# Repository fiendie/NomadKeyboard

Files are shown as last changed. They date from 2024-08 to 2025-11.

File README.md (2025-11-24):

# Nomad Keyboard

The Nomad is a 7×5 keys, column-staggered split keyboard based in part on the [Sofle Choc by Brian Low](https://github.com/brianlow/SofleKeyboard).
It uses low profile Kailh Choc v1 switches with hotswap sockets and features per-key RGB lighting via SK6812 Mini-E LEDs.
Compared to the Sofle Choc the nomad offers an additional thumb cluster key, an additional modifier key in the 5th row and a 7th inner column with 3 keys each.
An MX version is also available.

If you are a non-EU resident you can buy pre-made keyboards from [Lucky Boy Store](https://www.aliexpress.com/item/1005009922158971.html) on AliExpress.

## Table of Contents

- [Firmware](#firmware)
- [Bill of Materials](#bill-of-materials)
- [Default Layout](#default-layout)
- [Build Instructions](#build-instructions)
- [Images](#images)

## Firmware 

Nomad uses [QMK firmware](https://github.com/fiendie/qmk_firmware/tree/nomad)

Currently there is a default keymap for and a vial keymap to configure your keyboard in real time.

## Bill of Materials

| **Item** | **Quantity** | **Notes** |
|---|---|---|
| **Nomad PCB** | 2 | Custom left and right halves. |
| **Kailh Choc v1 or MX switches** | 68 | Choose based on version, the Choc version is only compatible with v1 switches!. |
| **Keycaps (MBK, ChocFox, or MX)** | 68 | Must match switch type and profile preference. |
| **SMD Diodes (1N4148, 0805 package)** | 68 | One per switch; surface-mount only. |
| **SK6812 Mini-E LEDs** | 68 | One per switch, make sure you get the Mini-E version specifically. |
| **RP2040 Controller** | 2 | Tested with SplitKB Liatris and 42.Keebs Frood. |
| **TRRS jacks** | 2 | For inter-half communication. |
| **TRRS cable** | 1 | Male-to-male, preferrably with 90 degree plugs |
| **ALPS EC12 Low-Profile Rotary Encoder** | 2 | Optional rotary input. |
| **Tactile Reset Button** | 2 | Optional but useful. |
| **OLED Display (SSD1306 128x32)** | 2 (optional) | Optional I2C displays. |
| **SMD Resistors (0805 package)** | 4 | I2C pull-up resistors, ony needed for the displays |
| **Header Pins** | Varies | For MCU, OLEDs. |
| **3D-Printed Case** | 2 halves | Top shell only; open-bottom design using included STL files. |
| **Acrylic Cover** | 2 halves | Laser-cut cover layer using included DXF file. |
| **M2 Standoffs (12 mm)** | 8 | For mounting cover to case. |
| **M2 Countersunk Screws (top)** | 8 | For securing the acrylic cover to standoffs. |
| **M2 Hex Screws (bottom of standoffs)**  | 8 | Attach standoffs from underneath the case edge. |
| **Rubber feet** | 8+ | Optional, for grip and elevation. |

## Default layout 

**Base Layer**
```
┌──────┬─────┬─────┬─────┬─────┬─────┬─────┐                ┌─────┬─────┬─────┬─────┬─────┬─────┬──────┐
│ Esc  │  1  │  2  │  3  │  4  │  5  │  <  │                │  >  │  6  │  7  │  8  │  9  │  0  │ Bksp │
├──────┼─────┼─────┼─────┼─────┼─────┼─────┤                ├─────┼─────┼─────┼─────┼─────┼─────┼──────┤
│ Tab  │  Q  │  W  │  E  │  R  │  T  │  {  │                │  }  │  Z  │  U  │  I  │  O  │  P  │  ?   │
├──────┼─────┼─────┼─────┼─────┼─────┼─────┤                ├─────┼─────┼─────┼─────┼─────┼─────┼──────┤
│  =   │  A  │  S  │  D  │  F  │  G  │  |  │                │  -  │  H  │  J  │  K  │  L  │  +  │  #   │
├──────┼─────┼─────┼─────┼─────┼─────┼─────┘                └─────┼─────┼─────┼─────┼─────┼─────┼──────┤
│ LSft │  Y  │  X  │  C  │  V  │  B  │                            │  N  │  M  │  ,  │  .  │  ↑  │ RSft │
├──────┼─────┼─────┼─────┼─────┼─────┼─────┬─────┐    ┌─────┬─────┼─────┼─────┼─────┼─────┼─────┼──────┤
│ Ctrl │ L3  │ L2  │ Opt │ GUI │     │ Spc │ Del │    │ L1  │ Rtn │     │ GUI │ Opt │  ←  │  ↓  │  →   │
└──────┴─────┴─────┴─────┴─────┘     └─────┴─────┘    └─────┴─────┘     └─────┴─────┴─────┴─────┴──────┘
```
**Symbol Layer**
```
┌──────┬─────┬─────┬─────┬─────┬─────┬─────┐                ┌─────┬─────┬─────┬─────┬─────┬─────┬──────┐
│      │     │     │     │     │     │  ^  │                │  °  │     │     │     │     │     │      │
├──────┼─────┼─────┼─────┼─────┼─────┼─────┤                ├─────┼─────┼─────┼─────┼─────┼─────┼──────┤
│      │  Q  │     │  €  │     │     │  [  │                │  ]  │     │  Ü  │     │  Ö  │     │      │
├──────┼─────┼─────┼─────┼─────┼─────┼─────┤                ├─────┼─────┼─────┼─────┼─────┼─────┼──────┤
│      │  Ä  │  ß  │     │     │     │  \  │                │  /  │  H  │     │     │  @  │     │      │
├──────┼─────┼─────┼─────┼─────┼─────┼─────┘                └─────┼─────┼─────┼─────┼─────┼─────┼──────┤
│      │     │     │     │     │     │                            │  ~  │     │     │     │     │      │
├──────┼─────┼─────┼─────┼─────┼─────┼─────┬─────┐    ┌─────┬─────┼─────┼─────┼─────┼─────┼─────┼──────┤
│      │     │     │     │     │     │     │     │    │     │     │     │     │     │     │     │      │
└──────┴─────┴─────┴─────┴─────┘     └─────┴─────┘    └─────┴─────┘     └─────┴─────┴─────┴─────┴──────┘
```
**FN/Media Layer**
```
┌──────┬─────┬─────┬─────┬─────┬─────┬─────┐                ┌─────┬─────┬─────┬─────┬─────┬─────┬──────┐
│      │ F1  │ F2  │ F3  │ F4  │ F5  │ F6  │                │ F7  │ F8  │ F9  │ F10 │ F11 │ F12 │      │
├──────┼─────┼─────┼─────┼─────┼─────┼─────┤                ├─────┼─────┼─────┼─────┼─────┼─────┼──────┤
│      │     │     │     │     │     │     │                │ B+  │     │     │     │     │     │      │
├──────┼─────┼─────┼─────┼─────┼─────┼─────┤                ├─────┼─────┼─────┼─────┼─────┼─────┼──────┤
│      │     │     │     │     │     │     │                │ B-  │     │     │     │     │     │      │
├──────┼─────┼─────┼─────┼─────┼─────┼─────┘                └─────┼─────┼─────┼─────┼─────┼─────┼──────┤
│      │     │     │     │     │     │                            │     │     │     │     │ PgU │ Ins  │
├──────┼─────┼─────┼─────┼─────┼─────┼─────┬─────┐    ┌─────┬─────┼─────┼─────┼─────┼─────┼─────┼──────┤
│      │     │     │     │ Rwd │     │ Pla │ Mut │    │ V-  │ V+  │     │ Fwd │     │ Hom │ PgD │ End  │
└──────┴─────┴─────┴─────┴─────┘     └─────┴─────┘    └─────┴─────┘     └─────┴─────┴─────┴─────┴──────┘
```
**RGB Settings Layer**
```
┌──────┬─────┬─────┬─────┬─────┬─────┬─────┐                ┌─────┬─────┬─────┬─────┬─────┬─────┬──────┐
│      │     │     │     │     │     │ Tgl │                │     │     │     │     │     │     │      │
├──────┼─────┼─────┼─────┼─────┼─────┼─────┤                ├─────┼─────┼─────┼─────┼─────┼─────┼──────┤
│      │     │     │     │     │     │ Md- │                │ Md+ │     │     │     │     │     │      │
├──────┼─────┼─────┼─────┼─────┼─────┼─────┤                ├─────┼─────┼─────┼─────┼─────┼─────┼──────┤
│      │     │     │     │     │     │ Sp- │                │ Sp+ │     │     │     │     │     │      │
├──────┼─────┼─────┼─────┼─────┼─────┼─────┘                └─────┼─────┼─────┼─────┼─────┼─────┼──────┤
│      │     │     │     │     │     │                            │     │     │     │     │     │      │
├──────┼─────┼─────┼─────┼─────┼─────┼─────┬─────┐    ┌─────┬─────┼─────┼─────┼─────┼─────┼─────┼──────┤
│      │     │     │     │ Va- │     │ H-  │ H+  │    │ S-  │ S+  │     │ Va+ │     │     │     │      │
└──────┴─────┴─────┴─────┴─────┘     └─────┴─────┘    └─────┴─────┘     └─────┴─────┴─────┴─────┴──────┘
```

## Build Instructions

Still a work in progress

## Images
Nomad Keyboard Left Half
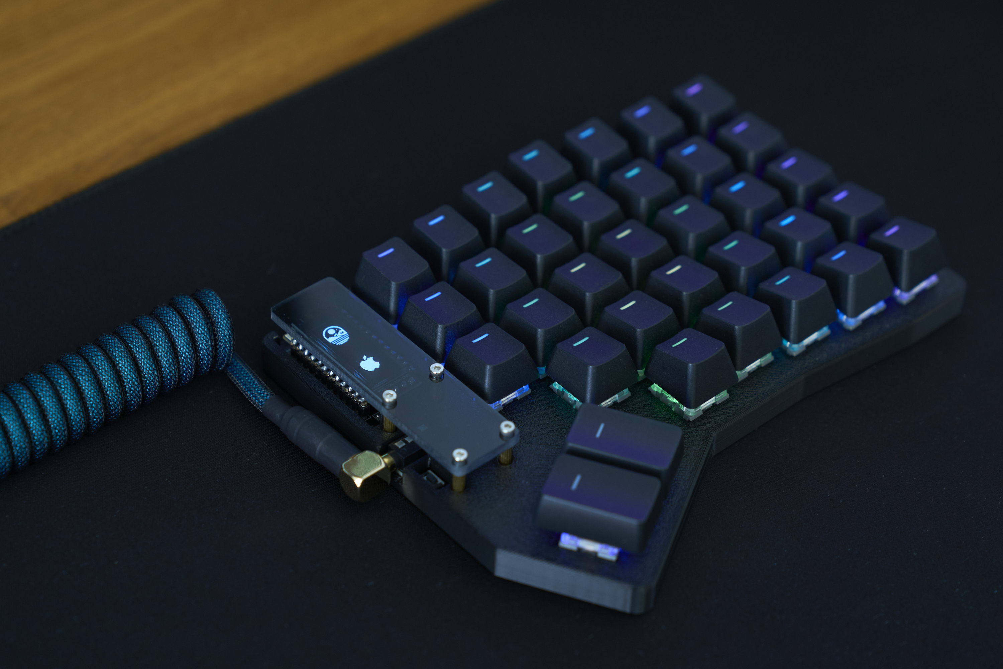
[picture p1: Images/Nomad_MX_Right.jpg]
Nomad Keyboard Left Half

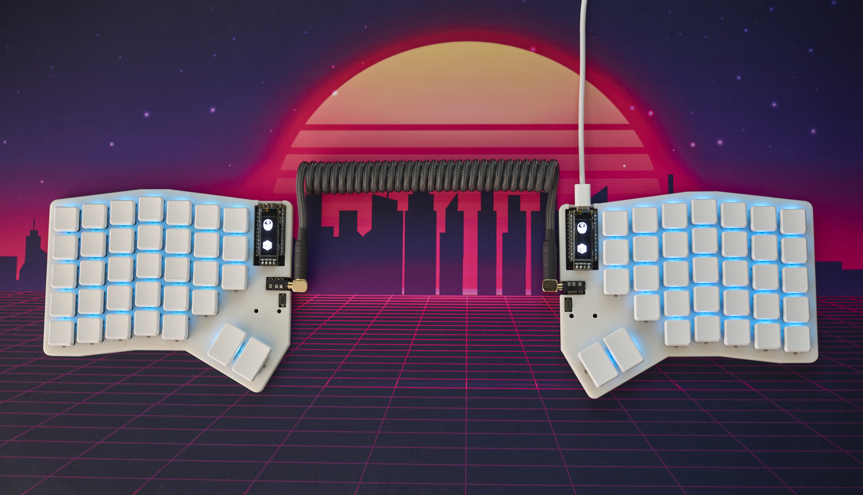
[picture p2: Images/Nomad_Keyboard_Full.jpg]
Nomad Keyboard Left Half

Nomad Keyboard PCB with Switches
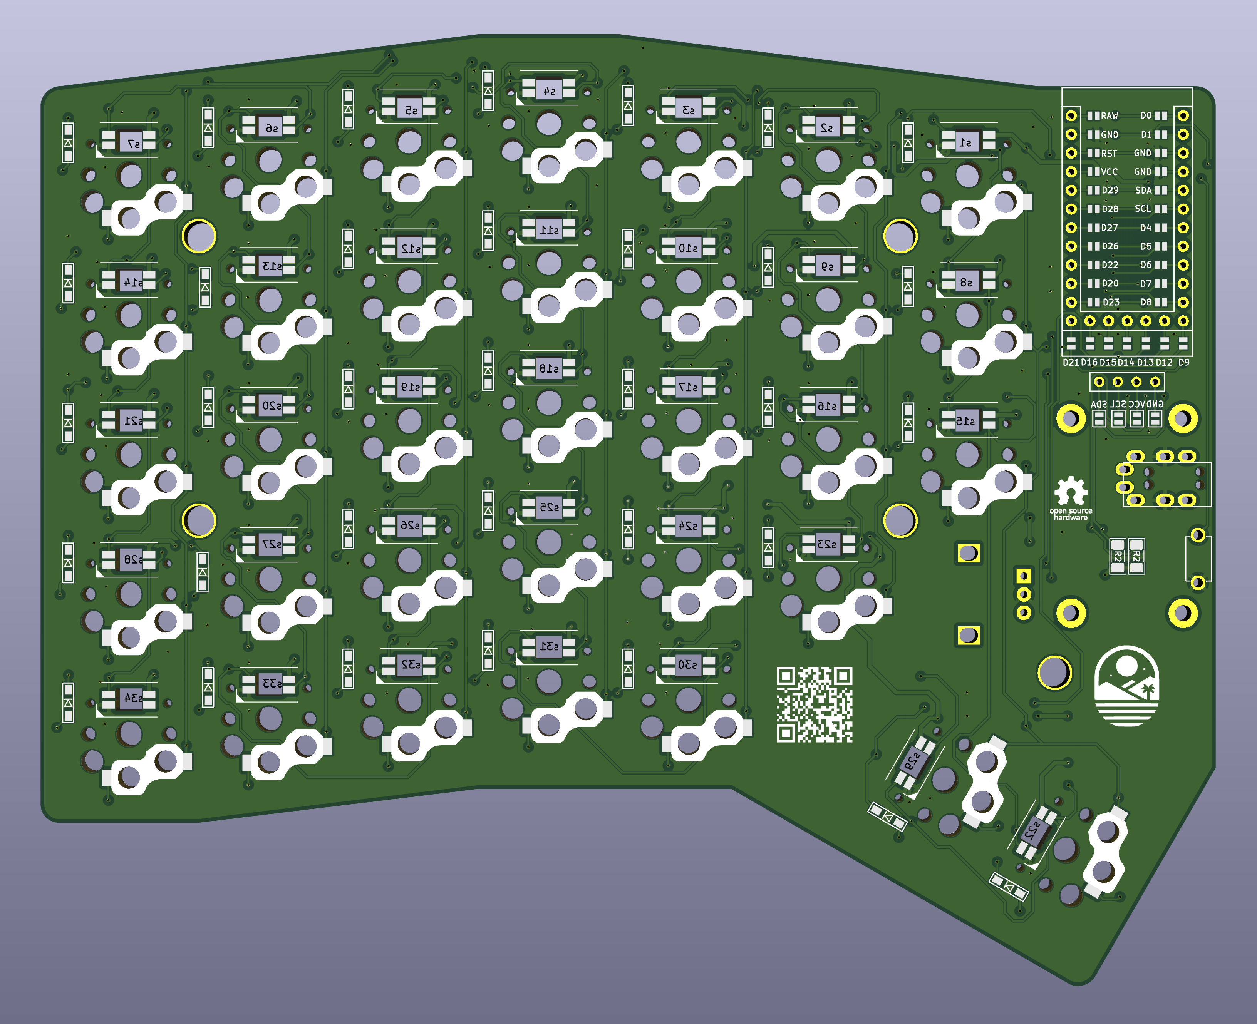
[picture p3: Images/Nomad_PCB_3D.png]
Nomad Keyboard PCB 3D View

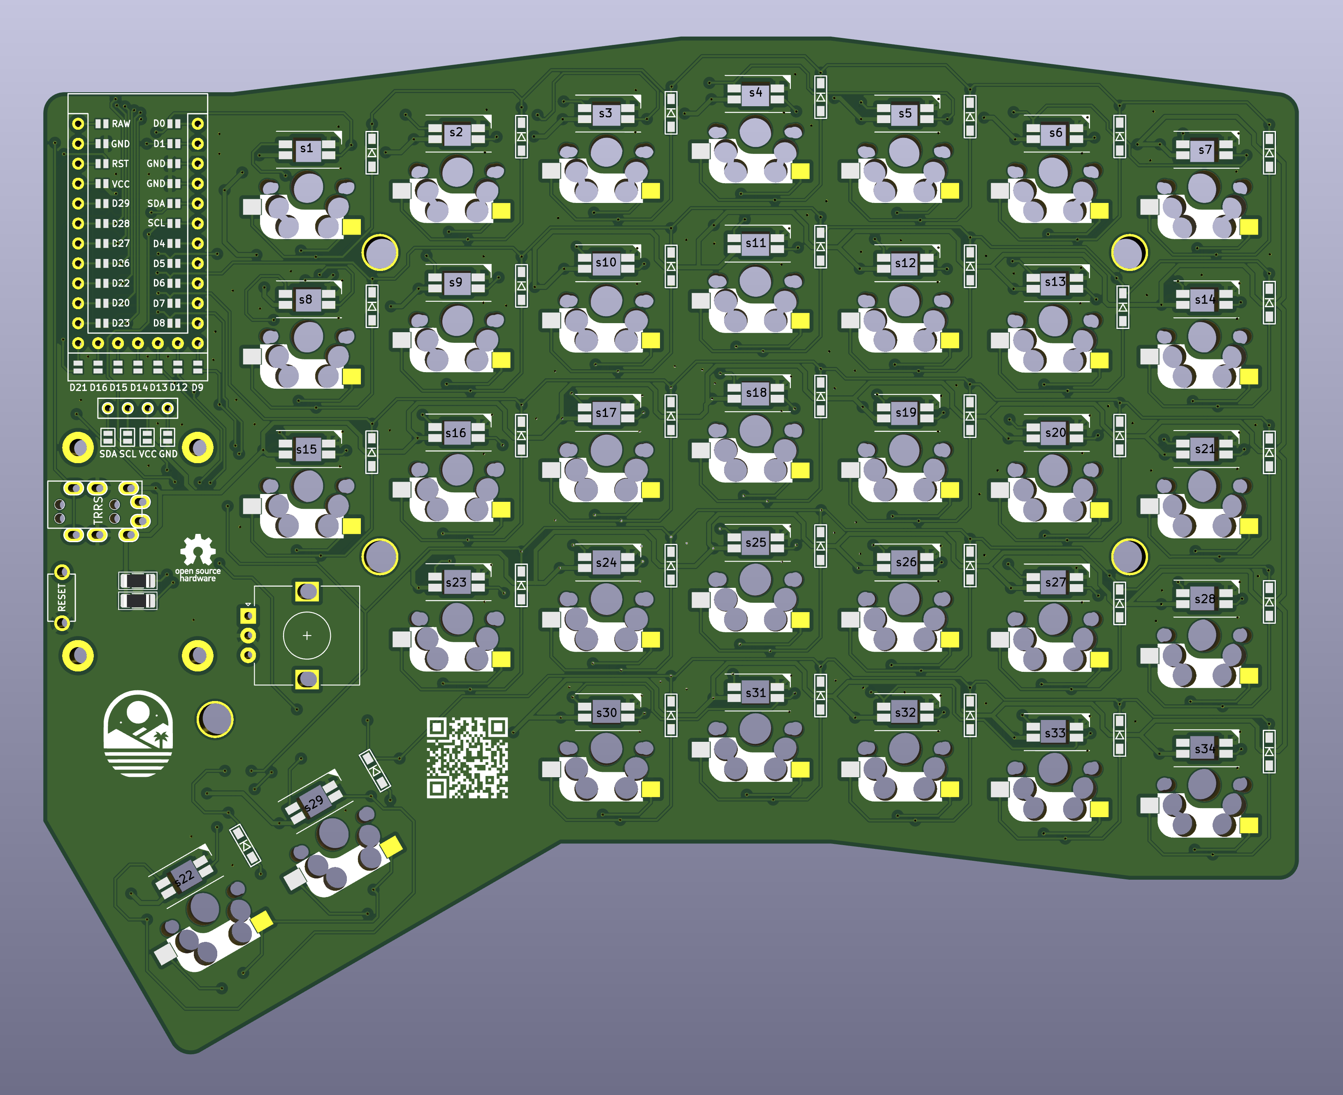
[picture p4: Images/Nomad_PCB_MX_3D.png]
Nomad Keyboard PCB 3D View


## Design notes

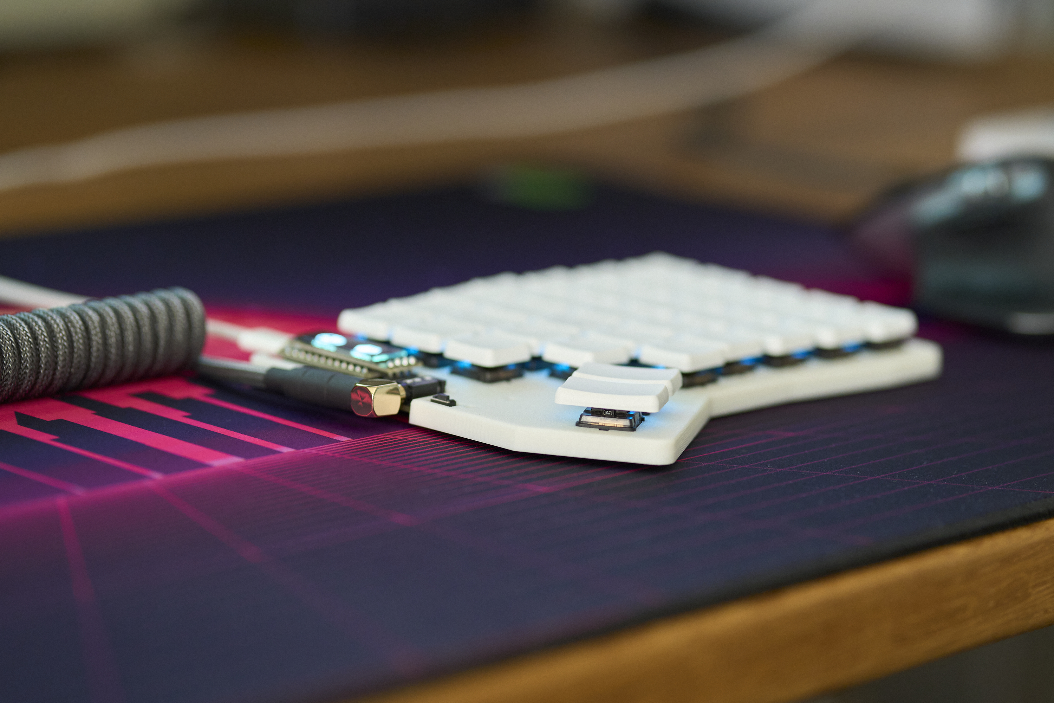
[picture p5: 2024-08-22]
Images/Nomad_Keyboard_Profile.jpg

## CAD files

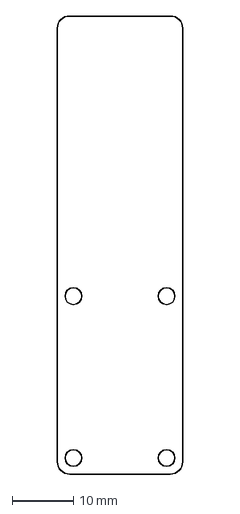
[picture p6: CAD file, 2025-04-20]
Case/Nomad_Display_Cover.dxf
20.5 x 75.0 mm

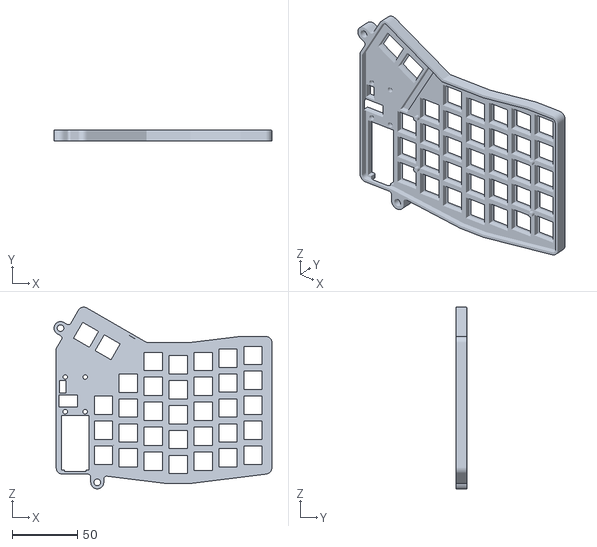
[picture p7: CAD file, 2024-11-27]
Case/Nomad_Keyboard_MX_Tenting_Case.stl
166.6 x 8.75 x 138.9

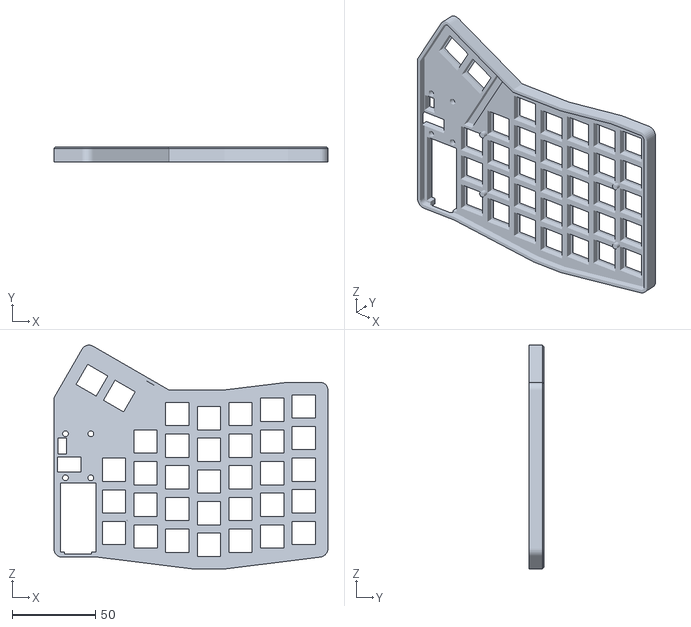
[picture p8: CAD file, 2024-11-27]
Case/Nomad_Keyboard_MX Case.stl
164.9 x 8.75 x 134.8

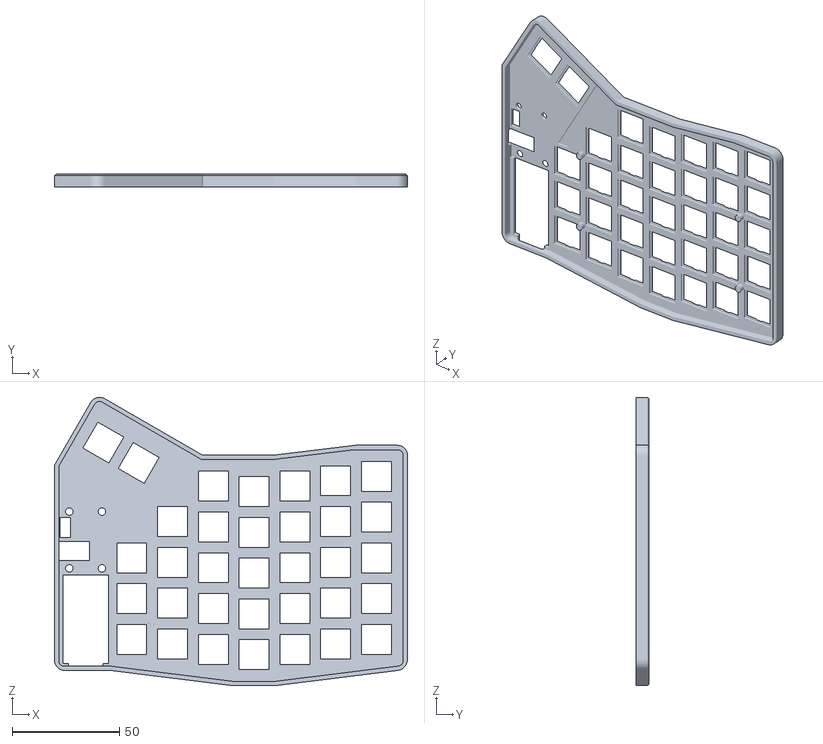
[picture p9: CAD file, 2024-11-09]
Case/Nomad_Keyboard_Case.stl
164.9 x 6.00 x 134.8

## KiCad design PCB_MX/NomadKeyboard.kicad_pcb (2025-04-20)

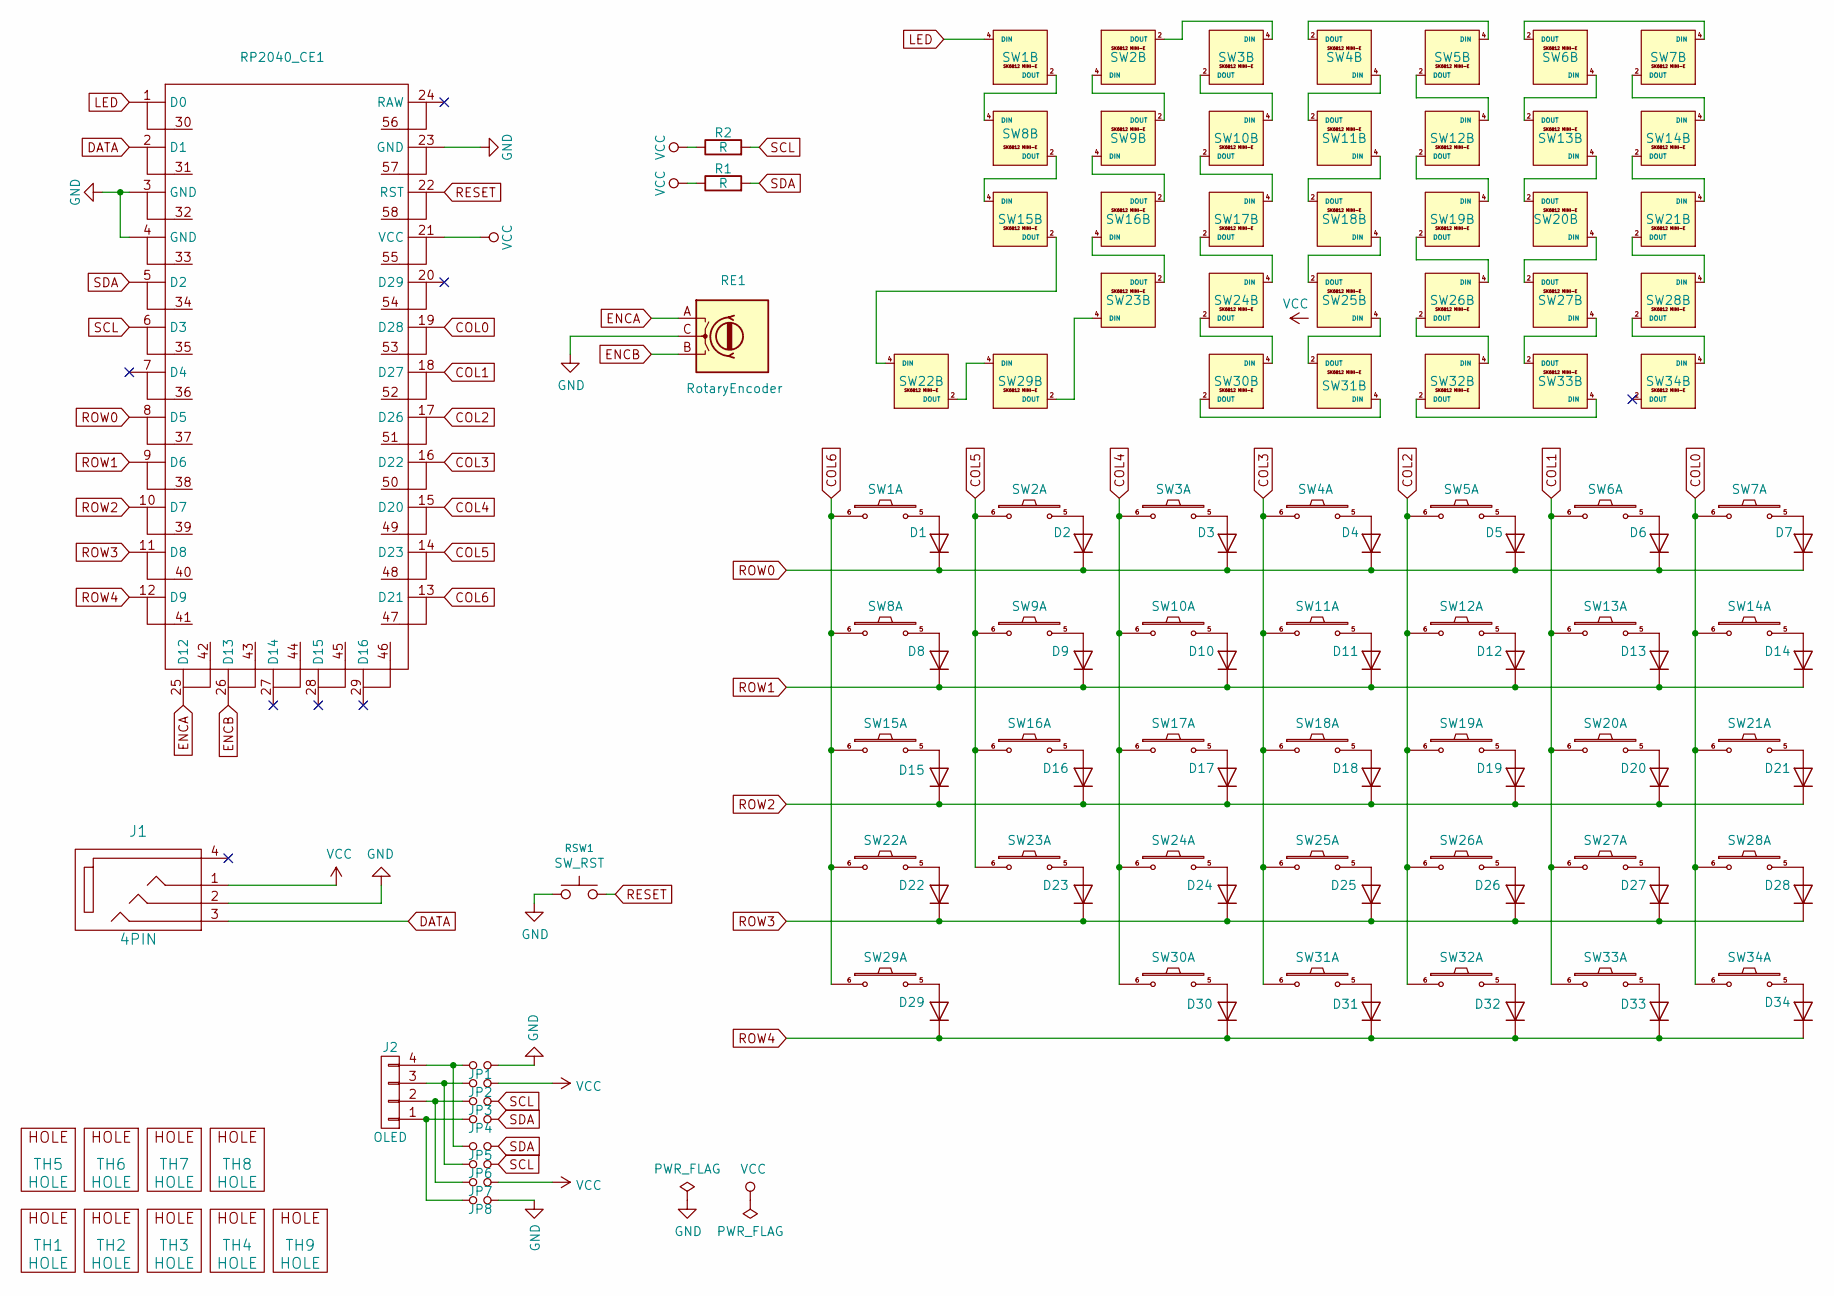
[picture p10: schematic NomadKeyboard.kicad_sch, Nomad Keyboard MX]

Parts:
D1, D2, D3, D4, D5, D6, D7, D8, D9, D10, D11, D12, D13, D14, D15, D16, D17, D18, D19, D20, D21, D22, D23, D24, D25, D26, D27, D28, D29, D30, D31, D32, D33, D34: D; crkbd-diode
J1: 4PIN; MJ-4PP-9
J2: OLED; OLED_4Pin
JP1, JP2, JP3, JP4, JP5, JP6, JP7, JP8: Jumper_NO_Small; Jumper
R1, R2: R; R_1206_3216Metric_Pad1.30x1.75mm_HandSolder
RE1: RotaryEncoder; RotaryEncoder_Alps_EC12E_Vertical_H20mm
RP2040_CE1: RP2040_CE
RSW1: SW_RST; TACT_SWITCH_TVBP06
SW1, SW2, SW3, SW4, SW5, SW6, SW7, SW8, SW9, SW10, SW11, SW12, SW13, SW14, SW15, SW16, SW17, SW18, SW19, SW20, SW21, SW22, SW23, SW24, SW25, SW26, SW27, SW28, SW29, SW30, SW31, SW32, SW33, SW34: SW_PUSH_LED; SK6812MINI-E_and_cherry
TH1, TH2, TH3, TH4, TH9: HOLE; HOLE_M2_TH
TH5, TH6, TH7, TH8: HOLE; M2_HOLE_PCB

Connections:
COL0: RP2040_CE1.19 (D28), SW7.6, SW14.6, SW21.6, SW28.6, SW34.6
COL1: RP2040_CE1.18 (D27), SW6.6, SW13.6, SW20.6, SW27.6, SW33.6
COL2: RP2040_CE1.17 (D26), SW5.6, SW12.6, SW19.6, SW26.6, SW32.6
COL3: RP2040_CE1.16 (D22), SW4.6, SW11.6, SW18.6, SW25.6, SW31.6
COL4: RP2040_CE1.15 (D20), SW3.6, SW10.6, SW17.6, SW24.6, SW30.6
COL5: RP2040_CE1.14 (D23), SW2.6, SW9.6, SW16.6, SW23.6
COL6: RP2040_CE1.13 (D21), SW1.6, SW8.6, SW15.6, SW22.6, SW29.6
DATA: J1.3, RP2040_CE1.2 (D1)
ENCA: RE1.A, RP2040_CE1.25 (D12)
ENCB: RE1.B, RP2040_CE1.26 (D13)
GND: J1.2, JP1.2, JP8.2, RE1.C, RP2040_CE1.3 (GND), RP2040_CE1.4 (GND), RP2040_CE1.23 (GND), RSW1.1, SW1.3 (GND), SW2.3 (GND), SW3.3 (GND), SW4.3 (GND), SW5.3 (GND), SW6.3 (GND), SW7.3 (GND), SW8.3 (GND), SW9.3 (GND), SW10.3 (GND), SW11.3 (GND), SW12.3 (GND), SW13.3 (GND), SW14.3 (GND), SW15.3 (GND), SW16.3 (GND), SW17.3 (GND), SW18.3 (GND), SW19.3 (GND), SW20.3 (GND), SW21.3 (GND), SW22.3 (GND), SW23.3 (GND), SW24.3 (GND), SW25.3 (GND), SW26.3 (GND), SW27.3 (GND), SW28.3 (GND), SW29.3 (GND), SW30.3 (GND), SW31.3 (GND), SW32.3 (GND), SW33.3 (GND), SW34.3 (GND)
LED: RP2040_CE1.1 (D0), SW1.4 (DIN)
unnamed: D1.2 (A), SW1.5
unnamed: D2.2 (A), SW2.5
unnamed: D3.2 (A), SW3.5
unnamed: D4.2 (A), SW4.5
unnamed: D5.2 (A), SW5.5
unnamed: D6.2 (A), SW6.5
unnamed: D7.2 (A), SW7.5
unnamed: D8.2 (A), SW8.5
unnamed: D9.2 (A), SW9.5
unnamed: D10.2 (A), SW10.5
unnamed: D11.2 (A), SW11.5
unnamed: D12.2 (A), SW12.5
unnamed: D13.2 (A), SW13.5
unnamed: D14.2 (A), SW14.5
unnamed: D15.2 (A), SW15.5
unnamed: D16.2 (A), SW16.5
unnamed: D17.2 (A), SW17.5
unnamed: D18.2 (A), SW18.5
unnamed: D19.2 (A), SW19.5
unnamed: D20.2 (A), SW20.5
unnamed: D21.2 (A), SW21.5
unnamed: D22.2 (A), SW22.5
unnamed: D23.2 (A), SW23.5
unnamed: D24.2 (A), SW24.5
unnamed: D25.2 (A), SW25.5
unnamed: D26.2 (A), SW26.5
unnamed: D27.2 (A), SW27.5
unnamed: D28.2 (A), SW28.5
unnamed: D29.2 (A), SW29.5
unnamed: D30.2 (A), SW30.5
unnamed: D31.2 (A), SW31.5
unnamed: D32.2 (A), SW32.5
unnamed: D33.2 (A), SW33.5
unnamed: D34.2 (A), SW34.5
unnamed: J2.1, JP4.1, JP8.1
unnamed: J2.2, JP3.1, JP7.1
unnamed: J2.3, JP2.1, JP6.1
unnamed: J2.4, JP1.1, JP5.1
unnamed: SW1.2 (DOUT), SW8.4 (DIN)
unnamed: SW2.4 (DIN), SW9.2 (DOUT)
unnamed: SW2.2 (DOUT), SW3.4 (DIN)
unnamed: SW4.2 (DOUT), SW5.4 (DIN)
unnamed: SW6.2 (DOUT), SW7.4 (DIN)
unnamed: SW3.2 (DOUT), SW10.4 (DIN)
unnamed: SW10.2 (DOUT), SW17.4 (DIN)
unnamed: SW11.4 (DIN), SW18.2 (DOUT)
unnamed: SW4.4 (DIN), SW11.2 (DOUT)
unnamed: SW5.2 (DOUT), SW12.4 (DIN)
unnamed: SW12.2 (DOUT), SW19.4 (DIN)
unnamed: SW13.4 (DIN), SW20.2 (DOUT)
unnamed: SW6.4 (DIN), SW13.2 (DOUT)
unnamed: SW7.2 (DOUT), SW14.4 (DIN)
unnamed: SW14.2 (DOUT), SW21.4 (DIN)
unnamed: SW8.2 (DOUT), SW15.4 (DIN)
unnamed: SW15.2 (DOUT), SW22.4 (DIN)
unnamed: SW16.4 (DIN), SW23.2 (DOUT)
unnamed: SW9.4 (DIN), SW16.2 (DOUT)
unnamed: SW17.2 (DOUT), SW24.4 (DIN)
unnamed: SW18.4 (DIN), SW25.2 (DOUT)
unnamed: SW19.2 (DOUT), SW26.4 (DIN)
unnamed: SW20.4 (DIN), SW27.2 (DOUT)
unnamed: SW21.2 (DOUT), SW28.4 (DIN)
unnamed: SW22.2 (DOUT), SW29.4 (DIN)
unnamed: SW23.4 (DIN), SW29.2 (DOUT)
unnamed: SW24.2 (DOUT), SW30.4 (DIN)
unnamed: SW25.4 (DIN), SW31.2 (DOUT)
unnamed: SW26.2 (DOUT), SW32.4 (DIN)
unnamed: SW27.4 (DIN), SW33.2 (DOUT)
unnamed: SW28.2 (DOUT), SW34.4 (DIN)
unnamed: SW30.2 (DOUT), SW31.4 (DIN)
unnamed: SW32.2 (DOUT), SW33.4 (DIN)
RESET: RP2040_CE1.22 (RST), RSW1.2
ROW0: D1.1 (K), D2.1 (K), D3.1 (K), D4.1 (K), D5.1 (K), D6.1 (K), D7.1 (K), RP2040_CE1.8 (D5)
ROW1: D8.1 (K), D9.1 (K), D10.1 (K), D11.1 (K), D12.1 (K), D13.1 (K), D14.1 (K), RP2040_CE1.9 (D6)
ROW2: D15.1 (K), D16.1 (K), D17.1 (K), D18.1 (K), D19.1 (K), D20.1 (K), D21.1 (K), RP2040_CE1.10 (D7)
ROW3: D22.1 (K), D23.1 (K), D24.1 (K), D25.1 (K), D26.1 (K), D27.1 (K), D28.1 (K), RP2040_CE1.11 (D8)
ROW4: D29.1 (K), D30.1 (K), D31.1 (K), D32.1 (K), D33.1 (K), D34.1 (K), RP2040_CE1.12 (D9)
SCL: JP3.2, JP6.2, R2.2, RP2040_CE1.6 (D3)
SDA: JP4.2, JP5.2, R1.2, RP2040_CE1.5 (D2)
VCC: J1.1, JP2.2, JP7.2, R1.1, R2.1, RP2040_CE1.21 (VCC), SW1.1 (VDD), SW2.1 (VDD), SW3.1 (VDD), SW4.1 (VDD), SW5.1 (VDD), SW6.1 (VDD), SW7.1 (VDD), SW8.1 (VDD), SW9.1 (VDD), SW10.1 (VDD), SW11.1 (VDD), SW12.1 (VDD), SW13.1 (VDD), SW14.1 (VDD), SW15.1 (VDD), SW16.1 (VDD), SW17.1 (VDD), SW18.1 (VDD), SW19.1 (VDD), SW20.1 (VDD), SW21.1 (VDD), SW22.1 (VDD), SW23.1 (VDD), SW24.1 (VDD), SW25.1 (VDD), SW26.1 (VDD), SW27.1 (VDD), SW28.1 (VDD), SW29.1 (VDD), SW30.1 (VDD), SW31.1 (VDD), SW32.1 (VDD), SW33.1 (VDD), SW34.1 (VDD)

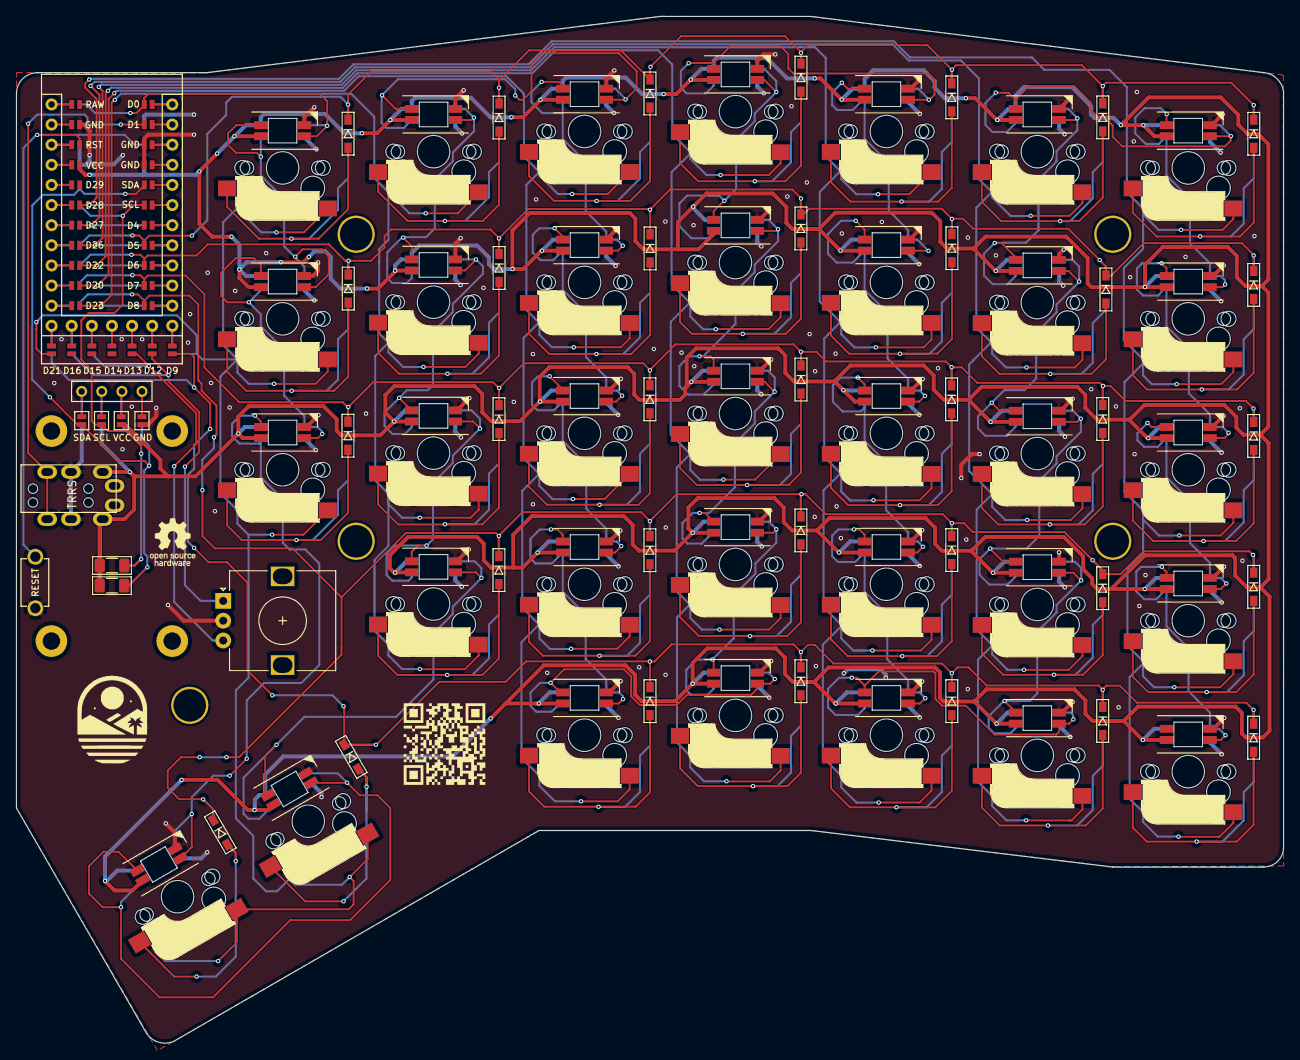
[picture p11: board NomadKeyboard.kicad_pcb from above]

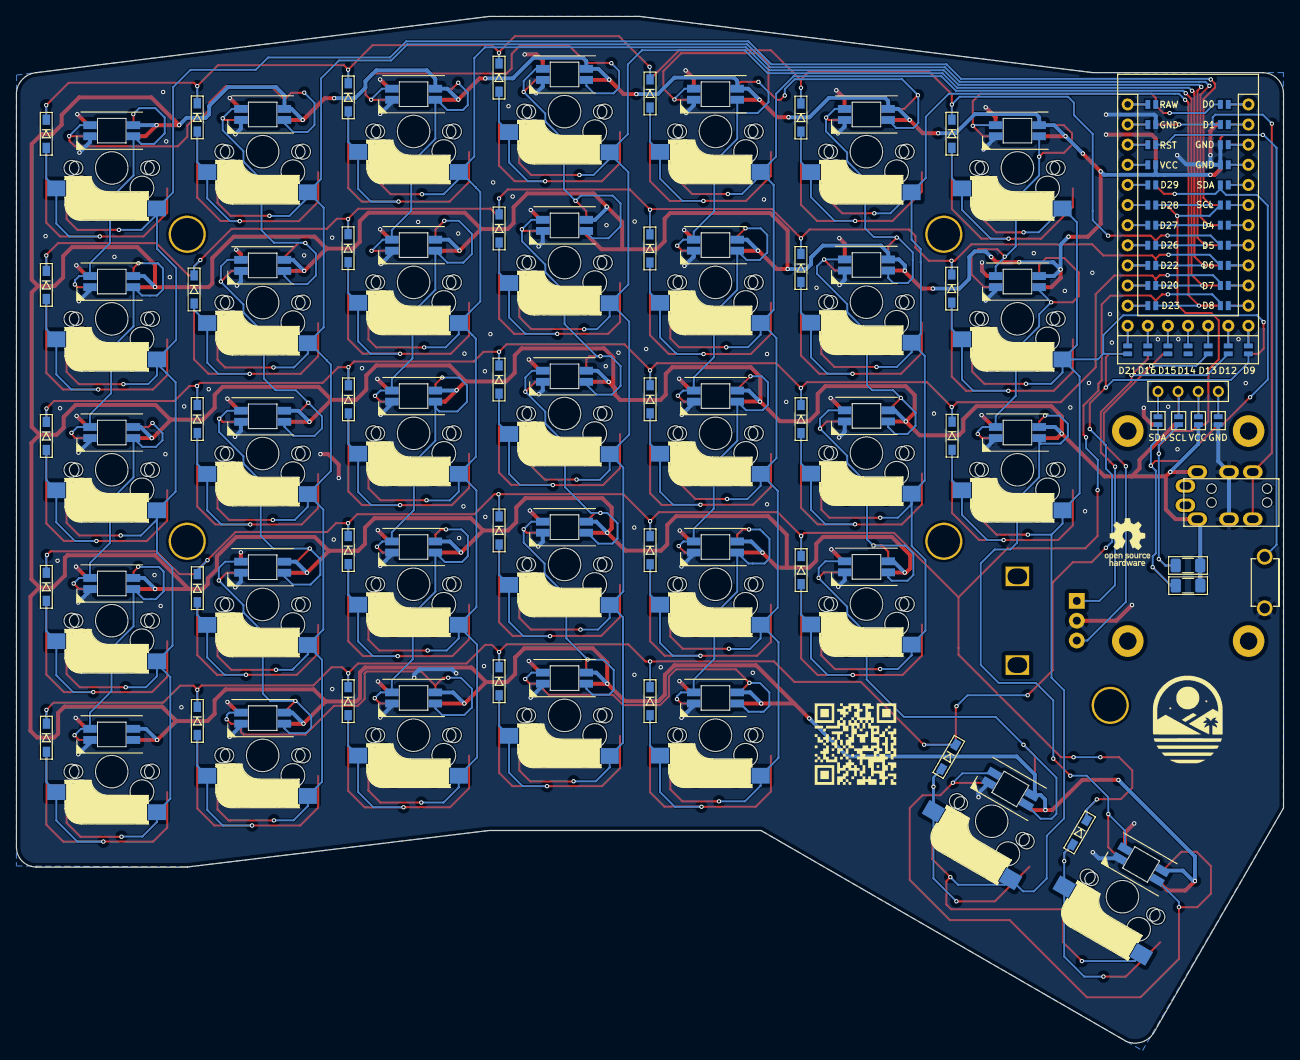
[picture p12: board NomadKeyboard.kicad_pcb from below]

Board: 2 copper layers, 159.9 x 129.6 mm, 98 parts (7 on the bottom side), 92 nets.

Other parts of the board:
L1, L2: LOGO; Nomad_Logo_20
OH1, OH2: OSHW-Logo_5.7x6mm_SilkScreen
QR1, QR2: QRCODE; Nomad_QR_Code

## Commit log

2024-08-16 First revision of the Nomad keyboard PCB
    [NomadKeyboard.kicad_sch]
2024-08-18 Additional mounting hole, Logo and QR Code on Silkscreen
    [NomadKeyboard.kicad_sch]
2024-09-16 Plated Mounting holes, STL File for top case, new Photos
    [NomadKeyboard.kicad_sch, Nomad_Keyboard_Case.stl]
2024-11-09 Added a new MX variant of the PCB, moved mounting holes for the display cover so the spacers don't interfere with the display
    [NomadKeyboard.dsn, NomadKeyboard.kicad_pcb, NomadKeyboard.kicad_sch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]
2024-11-13 Rotated thumb cluster keys on the MX version for 1.5U shine-through blank key caps
    [NomadKeyboard.kicad_pcb]
2024-11-13 Add tenting case for MX Version
    [Nomad_Keyboard_MX_Tenting_Case.stl]
2024-11-13 Update Gerber files for MX version
    [NomadKeyboard.kicad_pcb]
2024-11-27 Updated tenting case for MX version, added variant without tenting
    [Nomad_Keyboard_MX Case.stl, Nomad_Keyboard_MX_Tenting_Case.stl]
2025-01-12 Nomad Rev 2
    * Exclusively supports RP2040 CE microcontrollers
    * Only one set of headers for hte RP2040 with solder jumpers to select
    the half
    * EC12 low-profile rotary encoder support
    [NomadKeyboard.dsn, NomadKeyboard.kicad_pcb, NomadKeyboard.kicad_sch]
2025-01-14 Tweaked position of rotary encoder, updated Gerber files
    [NomadKeyboard.kicad_pcb]
2025-04-20 Updated page settings
    [NomadKeyboard.kicad_pcb, NomadKeyboard.kicad_sch]
2025-04-20 Addec BoM, updated photos
    [Nomad_Display_Cover.dxf]
2025-11-24 Updated README to incorporate store link, mention vial keymap and add LEDs to BOM
